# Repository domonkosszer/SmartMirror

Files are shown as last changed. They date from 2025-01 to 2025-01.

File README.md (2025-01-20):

# SmartMirror

Our project aims to develop an innovative Smart Mirror, enhanced with touchscreen interactivity through infrared light technology. By integrating both emitters and receivers of infrared light, the touchscreen detects user interactions by identifying interruptions in the light beams, enabling accurate coordinate detection. The primary goal is to create an interactive mirror featuring a display that responds seamlessly to touch inputs. This will allow users to interact with the display and switch between various applications.

To streamline the design and avoid tangled cables, we decided to solder all the connections. However, the soldering process proved more challenging than anticipated, preventing us from achieving the desired results. Additionally, we encountered issues with a loose connection to the screen, which led to flickering and occasional display anomalies, including distorted lighting effects.

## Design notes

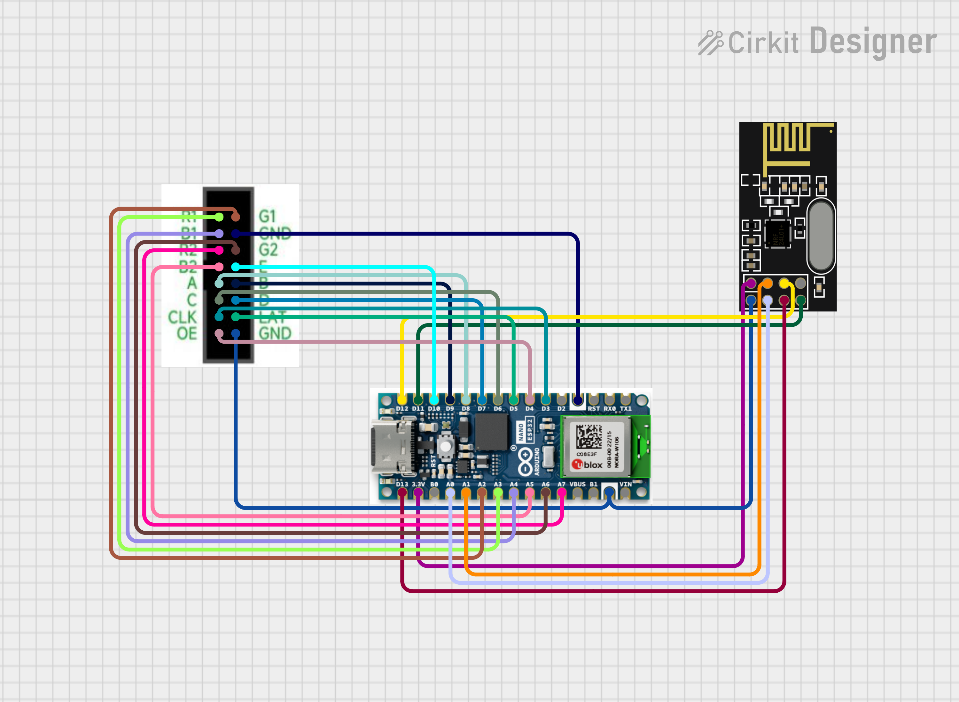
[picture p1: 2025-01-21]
images/circuit_image MainHub.png

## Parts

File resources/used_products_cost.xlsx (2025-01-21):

Quantity | Need | Buffer | Item | URL | Prize
1 | 1 | 0 | Mineralglas 40cm x 30cm | https://www.jumbo.ch/de/bauen-renovieren/glas-kunstglas/kunstglas/mineralglas--40--30-cm/p/3227387 | CHF 6.20
5 | 5 | 0 | NRF24L01 | https://de.aliexpress.com/item/1005005642753224.html
10 | 8 | 2 | Prototype Boards 2 cm x 8 cm | https://de.aliexpress.com/item/1005007204340724.html
5 | 4 | 1 | Prototype Boards 4 cm x 6 cm | https://de.aliexpress.com/item/1005007204340724.html
20 | 12 | 8 | Multiplexer CD4051BE | https://de.aliexpress.com/item/1005002394795142.html
4 | 4 | 0 | Typ-C Nano 3.0-Controller für Arduino CH340 USB-Treiber | https://de.aliexpress.com/item/1005007066680464.html
10 | 4 | 6 | 10uf 400V Kondensator | https://de.aliexpress.com/item/1005004387892193.html | V
1 | 1 | 0 | Matrix-LED-Bildschirm 64 pixel x 64 pixel | https://de.aliexpress.com/item/1005007767387150.html | CHF 31.86
100 | 96 | 4 | 5mm Infra-Red Emitters | https://amzn.eu/d/e0SbXlf
100 | 96 | 4 | 5mm Infra-Red Phototransistors | https://amzn.eu/d/bf8DKLu | V
100 | 96 | 4 | 100k Ohm Resistors | https://amzn.eu/d/hSxaTXH | CHF 16.87
1 | 1 | 0 | Hohlstecker DC 5.5 x 2.1 mm Buchse | https://www.fust.ch/de/p/tv-foto-gaming/kabel-haustechnik/stromkabel-stromzubehoer/netzteile/delock/hohlstecker-dc-5-5-x-2-1-mm-buchse-terminalblock-2-pin-862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 | CHF 0.50
1 | 1 | 0 | NodeMCU-32S, ESP32 WiFi+Bluetooth Development Board | https://www.waveshare.com/nodemcu-32s.htm | CHF 13.16
1 | 1 | 0 | C 110V-220V zu DC 5V 10A Netzteil | https://de.aliexpress.com/item/1005004458821253.html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
1 | 1 | 0 | Multi 4 in 1 USB C Lange Ladegerät Ladekabel | Multi 4 in 1 USB C Lange Ladegerät Ladekabel Mehrere Ports Lade Kabel Typ C Stecker für Handys - AliExpress 509 (https://de.aliexpress.com/item/1005004444269560.html)
50 | 20 | 30 | 100 Ohm Resistors | https://de.aliexpress.com/item/1005007010335100.html
1 | 1 | 0 | Kupferdraht 5m 20AWG | RV-Kupferdraht, flexibles Kabel, elektrisches PVC-Elektrokabel, 300/500 V, einadriger, mehradriger, flexibler Draht für Auto-Audio-Kabel - AliExpress 13 (https://de.aliexpress.com/item/1005005995948905.html) | V
1 | 1 | 0 | Isolierband 9mm 10m | Isolierband hitze beständiges Kabelbaum klebeband Klebeband wasserdichtes Klebeband isolierendes Kfz-Stoffband 5-tlg - AliExpress (https://de.aliexpress.com/item/1005007005495930.html) | CHF 15.16
1 | 1 | 0 | Mirror Foil | https://www.foliencenter24.com/solar-screen-alu-80c-sonnenschutzfolie-76cm | CHF 8.58
1 | 1 | 0 | Arduino Nano ESP32 | https://www.digitec.ch/de/s1/product/arduino-nano-esp32-with-headers-entwicklungsboard-kit-37112615 | CHF 23.90
 |  |  |  | Total cost: | CHF 116.23

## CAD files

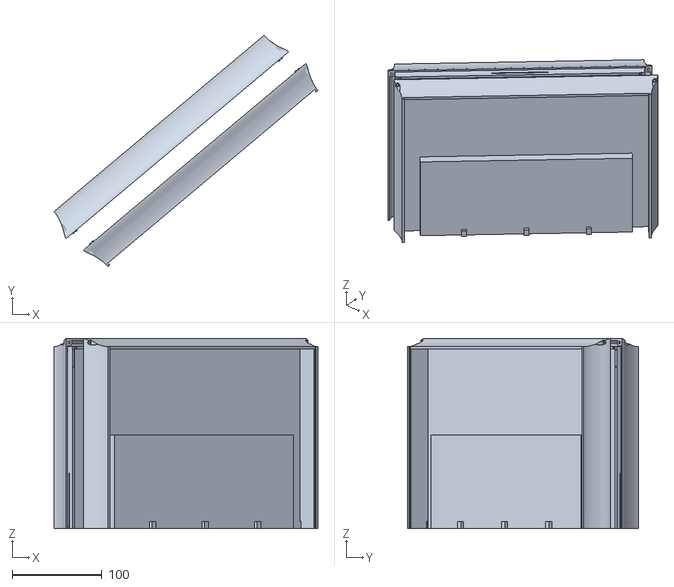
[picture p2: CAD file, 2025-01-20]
3D_models/Box_for_printing.stl
294.5 x 258.2 x 212.0

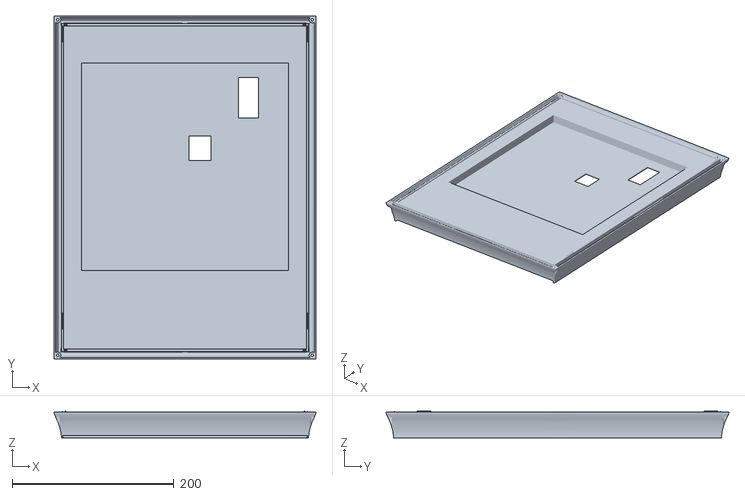
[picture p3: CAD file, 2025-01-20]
3D_models/Box.stl
324.0 x 424.0 x 33.1

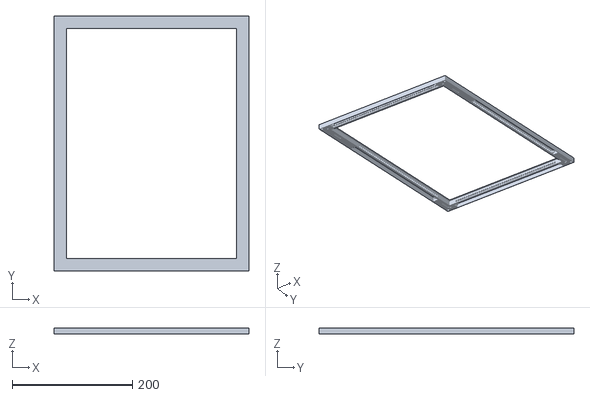
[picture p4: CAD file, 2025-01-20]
3D_models/Frame.stl
324.0 x 424.0 x 10.0

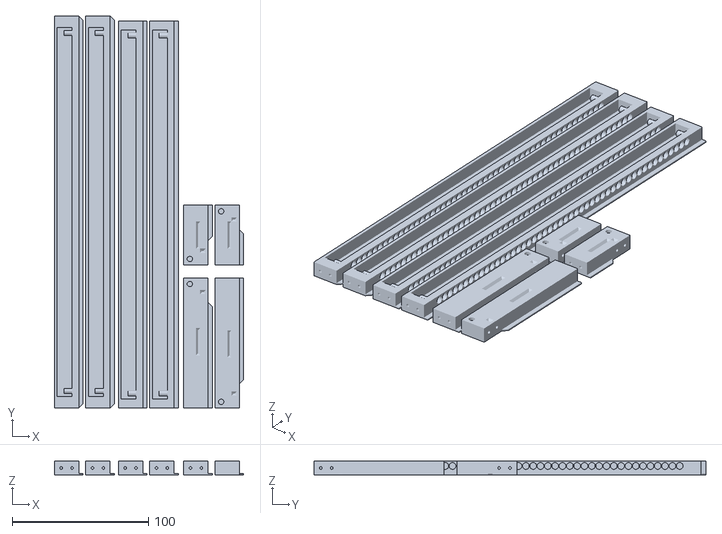
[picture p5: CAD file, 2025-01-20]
3D_models/Frame_for_printing.stl
139.0 x 288.0 x 10.0

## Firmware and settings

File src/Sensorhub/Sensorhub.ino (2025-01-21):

#include<SPI.h> 
#include<nRF24L01.h> 
#include<RF24.h> 
 
 
//enclosed is the code for multiplexer switching 
byte controlPinsLoneMux[] = {B00000000, //using switched digital pins to set the mux pins from 0-7 //enclosed is the code for multiplexer switching 
                             B10000000, //7.6.5.4.3.2.1.0 
                             B01000000, 
                             B11000000, 
                             B00100000, 
                             B10100000, 
                             B01100000, 
                             B11100000 
                            }; 
int muxValues[] = {0, 0, 0, 0, 0, 0, 0, 0, 0, 0, 0, 0, 0, 0, 0, 0, 0, 0, 0, 0, 0, 0, 0, 0}; 
int muxValuesA[] = {0, 0, 0, 0, 0, 0, 0, 0}; //holding  1-8 
int muxValuesB[] = {0, 0, 0, 0, 0, 0, 0, 0}; //holding  9-17 
int muxValuesC[] = {0, 0, 0, 0, 0, 0, 0, 0}; //holding  18-24 


int muxValuesZ[] = {0, 0, 0, 0, 0, 0, 0, 0, 0, 0, 0, 0, 0, 0, 0, 0, 0, 0, 0, 0, 0, 0, 0, 0};
byte muxValuesZA[] = {0, 0, 0, 0, 0, 0, 0, 0}; //holding  1-8 
byte muxValuesZB[] = {0, 0, 0, 0, 0, 0, 0, 0}; //holding  9-17 
byte muxValuesZC[] = {0, 0, 0, 0, 0, 0, 0, 0}; //holding  18-24 

int calValues[] = {0, 0, 0, 0, 0, 0, 0, 0, 0, 0, 0, 0, 0, 0, 0, 0, 0, 0, 0, 0, 0, 0, 0, 0}; 
int calValuesA[] = {0,0,0,0,0,0,0,0};
int calValuesB[] = {0,0,0,0,0,0,0,0};
int calValuesC[] = {0,0,0,0,0,0,0,0};

int calValuesZ[] = {0, 0, 0, 0, 0, 0, 0, 0, 0, 0, 0, 0, 0, 0, 0, 0, 0, 0, 0, 0, 0, 0, 0, 0}; 
int calValuesZA[] = {0,0,0,0,0,0,0,0};
int calValuesZB[] = {0,0,0,0,0,0,0,0};
int calValuesZC[] = {0,0,0,0,0,0,0,0};

bool lowSensors = false;
float lTouch = 0;
unsigned long lTtime = 0;
unsigned long lTclock = 0;
bool reset = true;

bool lowSensorsZX = false;
float lTouchZX = 0;
unsigned long lTtimeZX = 0;
unsigned long lTclockZX = 0;
bool resetZX = true;
 
int calibrate; 
int buttonPin = 14; 
bool printing; 
int calibrated; 
int eight; 
bool expiredCal; 
bool firstWrng; 
bool autocalibration = false; 
bool push; 
long OutputInterval = 1500; 
unsigned long rStart = 0;
long rIntrvl = 60000;
unsigned long BaseTime; 
unsigned long CurrentTime; 
unsigned long PreviousTime; 
unsigned long expired; 
bool expire; 
bool printrecal; 
unsigned long lastwrng; 
unsigned long calStart; 
unsigned long wrngStrt; 
unsigned int wrngIntrvl = 900000 /*30000*/; 
unsigned int expireIntrvl =  7200000 /*60000*/; 
bool adjusted = false;
unsigned long expireStrt; 
unsigned long expireLst; 
bool aligned; 
bool pushed; 
double IRsetting; 
bool calibrationStored = false;
bool calibratedZ = false;
unsigned long powerOnTime = 0;
long selfAdjTime = 500;
bool selfCal = false;

bool n = false;
bool t = false;
bool c = false;
bool d = false;
bool b = false;
bool z = false;
bool y = false;
bool r = false;

bool cPrinted = true;
bool dPrinted = true;
bool wrote = false;

unsigned long StartTime; 

int LowX = 0;
int Low1X = 0;
int Low2X = 0;
int Low3X = 0;
int Low4X = 0;
int lTrend = 0;
float lastX = 0;
float lastY = 0;

int highTouch1 = 0;
int highTouch2 = 0;
int highTouch3 = 0;
int lowTouch1 = 0;
int lowTouch2 = 0;
int lowTouch3 = 0;
int lastDiff = 0;
int currentDiff = 0;

int LowZX = 0;
int Low1ZX = 0;
int Low2ZX = 0;
int Low3ZX = 0;
int Low4ZX = 0;
int lTrendZX = 0;
float lastZX = 0;

int highTouch1ZX = 0;
int highTouch2ZX = 0;
int highTouch3ZX = 0;
int lowTouch1ZX = 0;
int lowTouch2ZX = 0;
int lowTouch3ZX = 0;
int lastDiffZX = 0;
int currentDiffZX = 0;

const int calTime = 2000; 
unsigned long currentCal; 
 
RF24 radio(8,9); 
 
//const uint64_t wAddress[] = {0xD31373D0B2LL};

const byte address[6] = "00001";

  
//const byte rxAddr[6] = "TRAN1"; 
 
void setup() { 
  Serial.begin(9600);
  radio.begin();
  radio.openWritingPipe(address);
  radio.setChannel(5);           
  radio.setDataRate(RF24_1MBPS);
  radio.setPALevel(RF24_PA_LOW);
  
  radio.stopListening();

  Serial.println("Transmitter ready.");


  DDRD = B11100000; //setting digital pins 6-4 to HIGH 
  BaseTime = millis(); 
  //pinMode(buttonPin, INPUT); 
  //pinMode(6, OUTPUT);
  //pinMode(5, OUTPUT); 
  //pinMode(4, OUTPUT); 
  pinMode(10, OUTPUT); 
  pinMode(14, OUTPUT);  //receivers
  digitalWrite(14, HIGH); 
  pinMode(15, OUTPUT);  //receivers
  digitalWrite(15, HIGH); 
} 
 
void setPinMux(int outputMuxPin) { 
  PORTD = controlPinsLoneMux[outputMuxPin];       //setting sewdxa{;;e'f}digital 4-6 to follow the truth table instructions 
 
} 

void muxVals() {
  Serial.println();
  Serial.println(F("Values for multiplexer:"));
  Serial.println(F("==========================="));
  for (int a = 0; a < 24; a++) {
    Serial.print(a);
    Serial.print(F(" = "));
    Serial.println(muxValues[a]);
  }
  Serial.println(F("==========================="));
} 

void muxValsZ() {
  Serial.println();
  Serial.println(F("Values for multiplexer Z:"));
  Serial.println(F("==========================="));
  for (int a = 0; a < 24; a++) {
    Serial.print(a);
    Serial.print(F(" = "));
    Serial.println(muxValuesZ[a]);
  }
  Serial.println(F("==========================="));
} 
 
void calVals() { 
  Serial.println(); 
  Serial.println(F("Calibrated Values:")); 
  Serial.println(F("===========================")); 
  for (int a = 0; a < 24; a++) { 
    Serial.print(a); 
    Serial.print(F(" = ")); 
    Serial.println(calValues[a]); 
  } 
  Serial.println(F("===========================")); 
} 

void calMuxDiff() { 
  Serial.println(); 
  Serial.println(F("Current Difference Between Calibrated Values and Current Values:")); 
  Serial.println(F("===========================")); 
 for (int a = 0; a < 24; a++){ 
    Serial.print(a); 
    Serial.print(F(" = ")); 
    Serial.println(muxValues[a] - calValues[a]); 
 }
  Serial.println(F("==========================="));
}

void calMuxDiffZA() { 
  Serial.println(); 
  Serial.println(F("Current Difference Between Calibrated Values and Current ZY Values:")); 
  Serial.println(F("===========================")); 
 for (int a = 0; a < 8; a++){ 
    Serial.print(a); 
    Serial.print(F(" = ")); 
    Serial.println(muxValuesZA[a] - calValuesA[a]); 
 }
  Serial.println(F("===========================")); 
}

void calMuxDiffZB(){
 for (int a = 0; a < 8; a++){
  for (int b = 8; b <16; b++){ 
  if ( a == 0 && b == 8){
    Serial.print(b); 
    Serial.print(F(" = ")); 
    Serial.println(muxValuesZB[a] - calValuesZB[a]);
  } 
  if ( a == 1 && b == 9){
    Serial.print(b); 
    Serial.print(F(" = ")); 
    Serial.println(muxValuesZB[a] - calValuesZB[a]);
  } 
  if ( a == 2 && b == 10){
    Serial.print(b); 
    Serial.print(F(" = ")); 
    Serial.println(muxValuesZB[a] - calValuesZB[a]);
  } 
  if ( a == 3 && b == 11){
    Serial.print(b); 
    Serial.print(F(" = ")); 
    Serial.println(muxValuesZB[a] - calValuesZB[a]);
  } 
  if ( a == 4 && b == 12){
    Serial.print(b); 
    Serial.print(F(" = ")); 
    Serial.println(muxValuesZB[a] - calValuesZB[a]);
  } 
  if ( a == 5 && b == 13){
    Serial.print(b); 
    Serial.print(F(" = ")); 
    Serial.println(muxValuesZB[a] - calValuesZB[a]);
  } 
  if ( a == 6 && b == 14){
    Serial.print(b); 
    Serial.print(F(" = ")); 
    Serial.println(muxValuesZB[a] - calValuesZB[a]);
  } 
  if ( a == 7 && b == 15){
    Serial.print(b); 
    Serial.print(F(" = ")); 
    Serial.println(muxValuesZB[a] - calValuesZB[a]);
  } 
 }
 }
  Serial.println(F("==========================="));
  
}

void calMuxDiffZC(){
 for (int a = 0; a < 8; a++){ 
  for (int b = 16; b < 24; b++){
   if ( a == 0 && b == 16){
    Serial.print(b); 
    Serial.print(F(" = ")); 
    Serial.println(muxValuesZC[a] - calValuesZC[a]); 
   }
   if ( a == 1 && b == 17){
    Serial.print(b); 
    Serial.print(F(" = ")); 
    Serial.println(muxValuesZC[a] - calValuesZC[a]); 
   }
   if ( a == 2 && b == 18){
    Serial.print(b); 
    Serial.print(F(" = ")); 
    Serial.println(muxValuesZC[a] - calValuesZC[a]); 
   }
   if ( a == 3 && b == 19){
    Serial.print(b); 
    Serial.print(F(" = ")); 
    Serial.println(muxValuesZC[a] - calValuesZC[a]); 
   }
   if ( a == 4 && b == 20){
    Serial.print(b); 
    Serial.print(F(" = ")); 
    Serial.println(muxValuesZC[a] - calValuesZC[a]); 
   }
   if ( a == 5 && b == 21){
    Serial.print(a); 
    Serial.print(F(" = ")); 
    Serial.println(muxValuesZC[a] - calValuesZC[a]); 
   }
   if ( a == 6 && b == 22){
    Serial.print(b); 
    Serial.print(F(" = ")); 
    Serial.println(muxValuesZC[a] - calValuesZC[a]); 
   }
   if ( a == 7 && b == 23){
    Serial.print(b); 
    Serial.print(F(" = ")); 
    Serial.println(muxValuesZC[a] - calValuesZC[a]); 
   }
 }
 }
  Serial.println(F("===========================")); 
}

  void muxValsZ3() { 
  for (int c1 = 0; c1 < 8; c1++) { 
  for (int c = 16; c < 24; c++) { 
  if (c == 16 && c1 == 0){ 
    Serial.print(F("ZX"));
    Serial.print(c); 
    Serial.print(F(" = "));  
    Serial.println(muxValuesZC[c1]); 
  } 
  if (c == 17 && c1 == 1){ 
    Serial.print(F("ZX"));
    Serial.print(c); 
    Serial.print(F(" = "));  
    Serial.println(muxValuesZC[c1]); 
  } 
  if (c == 18 && c1 == 2){ 
    Serial.print(F("ZX"));
    Serial.print(c); 
    Serial.print(F(" = "));  
    Serial.println(muxValuesZC[c1]); 
  } 
  if (c == 19 && c1 == 3){
    Serial.print(F("ZX")); 
    Serial.print(c); 
    Serial.print(F(" = "));  
    Serial.println(muxValuesZC[c1]); 
  } 
  if (c == 20 && c1 == 4){ 
    Serial.print(F("ZX"));
    Serial.print(c); 
    Serial.print(F(" = "));  
    Serial.println(muxValuesZC[c1]); 
  } 
  if (c == 21 && c1 == 5){ 
    Serial.print(F("ZX"));
    Serial.print(c); 
    Serial.print(F(" = "));  
    Serial.println(muxValuesZC[c1]); 
  } 
  if (c == 22 && c1 == 6){ 
    Serial.print(F("ZX"));
    Serial.print(c); 
    Serial.print(F(" = "));  
    Serial.println(muxValuesZC[c1]); 
  } 
  if (c == 23 && c1 == 7){
    Serial.print(F("ZX")); 
    Serial.print(c); 
    Serial.print(F(" = "));  
    Serial.println(muxValuesZC[c1]); 
  } 
  } 
  }  
     
   
  Serial.println(F("===========================")); 
} 
 

 
void timeloop(){ 
currentCal = millis(); 
} 

bool calArray (){
LowX = 0;
Low1X = 0;
Low2X = 0;
Low3X = 0;
Low4X = 0;

LowZX = 0;
Low1ZX = 0;
Low2ZX = 0;
Low3ZX = 0;
Low4ZX = 0;

int threesX = 0;
int twoosX = 0;
int onesX = 0;
int zeroesX = 0;

int threesZX = 0;
int twoosZX = 0;
int onesZX = 0;
int zeroesZX = 0;

bool low = true;
bool paired = false;
   
   calValues[0] = muxValues[0];
   calValues[1] = muxValues[1];
   calValues[2] = muxValues[2];
   calValues[3] = muxValues[3];
   calValues[4] = muxValues[4];
   calValues[5] = muxValues[5];
   calValues[6] = muxValues[6];
   calValues[7] = muxValues[7];
   calValues[8] = muxValues[8];
   calValues[9] = muxValues[9];
   calValues[10] = muxValues[10];
   calValues[11] = muxValues[11];
   calValues[12] = muxValues[12];
   calValues[13] = muxValues[13];
   calValues[14] = muxValues[14];
   calValues[15] = muxValues[15];
   calValues[16] = muxValues[16];
   calValues[17] = muxValues[17];
   calValues[18] = muxValues[18];
   calValues[19] = muxValues[19];
   calValues[20] = muxValues[20];
   calValues[21] = muxValues[21];
   calValues[22] = muxValues[22];
   calValues[23] = muxValues[23];

   calValuesZ[0] = muxValuesZ[0];
   calValuesZ[1] = muxValuesZ[1];
   calValuesZ[2] = muxValuesZ[2];
   calValuesZ[3] = muxValuesZ[3];
   calValuesZ[4] = muxValuesZ[4];
   calValuesZ[5] = muxValuesZ[5];
   calValuesZ[6] = muxValuesZ[6];
   calValuesZ[7] = muxValuesZ[7];
   calValuesZ[8] = muxValuesZ[8];
   calValuesZ[9] = muxValuesZ[9];
   calValuesZ[10] = muxValuesZ[10];
   calValuesZ[11] = muxValuesZ[11];
   calValuesZ[12] = muxValuesZ[12];
   calValuesZ[13] = muxValuesZ[13];
   calValuesZ[14] = muxValuesZ[14];
   calValuesZ[15] = muxValuesZ[15];
   calValuesZ[16] = muxValuesZ[16];
   calValuesZ[17] = muxValuesZ[17];
   calValuesZ[18] = muxValuesZ[18];
   calValuesZ[19] = muxValuesZ[19];
   calValuesZ[20] = muxValuesZ[20];
   calValuesZ[21] = muxValuesZ[21];
   calValuesZ[22] = muxValuesZ[22];
   calValuesZ[23] = muxValuesZ[23];

for (int a:calValuesA){
  if (a == 0) ++zeroesX;
  if (a == 1) ++onesX;
  if (a == 2) ++twoosX;
  if (a == 3) ++threesX;
}

for (int b:calValuesB){
  if (b == 0) ++zeroesX;
  if (b == 1) ++onesX;
  if (b == 2) ++twoosX;
  if (b == 3) ++threesX;
}

for (int c:calValuesC){
  if (c == 0) ++zeroesX;
  if (c == 1) ++onesX;
  if (c == 2) ++twoosX;
  if (c == 3) ++threesX;
}

for (int a:calValuesZA){
  if (a == 0) ++zeroesZX;
  if (a == 1) ++onesZX;
  if (a == 2) ++twoosZX;
  if (a == 3) ++threesZX;
}

for (int b:calValuesZB){
  if (b == 0) ++zeroesZX;
  if (b == 1) ++onesZX;
  if (b == 2) ++twoosZX;
  if (b == 3) ++threesZX;
}

for (int c:calValuesZC){
  if (c == 0) ++zeroesZX;
  if (c == 1) ++onesZX;
  if (c == 2) ++twoosZX;
  if (c == 3) ++threesZX;
}
  calibrationStored = true;
  paired = true;   
  low = false;  
Serial.println();
Serial.print(F("Calibration Successful! "));

Serial.println();
Serial.print("Calibration Failed!");

Serial.println();
Serial.print("There are this many zeroes for X: ");
Serial.print(zeroesX);

Serial.println();
Serial.print("There are this many ones for X: ");
Serial.print(onesX);
    
Serial.println();
Serial.print("There are this many twoos for X: ");
Serial.print(twoosX);
  
Serial.println();
Serial.print("There are this many threes for X: ");
Serial.print(threesX);

Serial.println();
Serial.print("There are this many zeroes for ZX: ");
Serial.print(zeroesZX);

Serial.println();
Serial.print("There are this many ones for ZX: ");
Serial.print(onesZX);
    
Serial.println();
Serial.print("There are this many twoos for ZX: ");
Serial.print(twoosZX);
  
Serial.println();
Serial.print("There are this many threes for ZX: ");
Serial.print(threesZX);

return paired; 
}

void loop() {   
lTclock = millis();

char input = 'O';
bool written = true;

float TouchedX = {0};
float TouchedZX = {0};
bool TouchX = false;
bool TouchZX = false;
bool tapped = false;  
unsigned long tappedTime = NULL;  
bool fingerDown = false;  

float touchedValuesX[] = {0,0,0,0,0,0,0,0,0,0,0,0,0,0,0,0,0,0,0,0,0,0,0,0};
float touchedValuesZX[] = {0,0,0,0,0,0,0,0,0,0,0,0,0,0,0,0,0,0,0,0,0,0,0,0};
float sendingX[] = {0,0}; 
float sendingZX[] = {0,0};     
  
bool sent = false;
 
byte message = 3; 

CurrentTime = millis(); 
calibrate = digitalRead(buttonPin); 
     
if (autocalibration == true){ 
expire = false; 
autocalibration = false; 
calStart = millis(); 
expireStrt = millis(); 
push = true; 
pushed = true; 
expire = false; 
firstWrng = false; 
calibrated = 2; 
calArray();
} 
   
if(calibrate == HIGH){ // added for the recal printing glitch 
 printrecal = false;   
  } 

 while (pushed == true){ 
  currentCal = millis(); 
  BaseTime = millis(); 
Serial.flush(); 
Serial.println();   
if (printrecal == false){ 
Serial.print(F("Calibrating..."));  
} 
else { 
  Serial.print(F("Auto-recalibrating...")); 
}  
if (currentCal <= calStart + calTime){   
    pushed = false; ;  
  } 
 }
   

if (CurrentTime - expireStrt >= 7200000 && CurrentTime - expireStrt >= expireIntrvl && firstWrng != true ){  
Serial.println(); 
Serial.print(F("It has been 2 hours since the last calibration, you should consider recalibrating.")); 
expireStrt = millis(); 
expired = millis(); 
expire = true; 
firstWrng = true; 
wrngStrt = millis(); 
calibrated = 1; 
} 
 
if (firstWrng == true && CurrentTime - wrngIntrvl >= wrngStrt ){ 
Serial.println(); 
Serial.print(F("Recalibration recommended!")); 
wrngStrt = millis(); 
lastwrng = millis(); 
 
    } 
 
 if (expire == true && CurrentTime - 1860000 >= expired && expired > 1) { // expired > 1 added for gltch 
  autocalibration = true; 
  printrecal = true; 
 }  
 
if (expire == true && CurrentTime - 7200000 >= expired){ 
  calibrated = 0; 
} 
for(int b = 8; b < 24; b ++){
 for (int a = 0; a < 8; a++) { 
    setPinMux(a);
    muxValuesZ[a] = analogRead(2);
    muxValues[a] = analogRead(5);
    if( a == 0 && b == 8){
      muxValues[b] =  analogRead(6);
      muxValuesZ[b] =  analogRead(3);
    }
    if( a == 1 && b == 9){
      muxValues[b] =  analogRead(6);
      muxValuesZ[b] =  analogRead(3);
    }
    if( a == 2 && b == 10){
      muxValues[b] =  analogRead(6);
      muxValuesZ[b] =  analogRead(3);
    }
    if( a == 3 && b == 11){
      muxValues[b] =  analogRead(6);
      muxValuesZ[b] =  analogRead(3);
    }
    if( a == 4 && b == 12){
      muxValues[b] =  analogRead(6);
      muxValuesZ[b] =  analogRead(3);
    }
    if( a == 5 && b == 13){
      muxValues[b] =  analogRead(6);
      muxValuesZ[b] =  analogRead(3);
    }
    if( a == 6 && b == 14){
      muxValues[b] =  analogRead(6);
      muxValuesZ[b] =  analogRead(3);
    }
    if( a == 7 && b == 15){
      muxValues[b] =  analogRead(6);
      muxValuesZ[b] =  analogRead(3);
    }
    if( a == 0 && b == 16){
      muxValues[b] =  analogRead(7);
      muxValuesZ[b] =  analogRead(4);
    }
    if( a == 1 && b == 17){
      muxValues[b] =  analogRead(7);
      muxValuesZ[b] =  analogRead(4);
    }
    if( a == 2 && b == 18){
      muxValues[b] =  analogRead(7);
      muxValuesZ[b] =  analogRead(4);
    }
    if( a == 3 && b == 19){
      muxValues[b] =  analogRead(7);
      muxValuesZ[b] =  analogRead(4);
    }
    if( a == 4 && b == 20){
      muxValues[b] =  analogRead(7);
      muxValuesZ[b] =  analogRead(4);
    }
    if( a == 5 && b == 21){
      muxValues[b] =  analogRead(7);
      muxValuesZ[b] =  analogRead(4);
    }
    if( a == 6 && b == 22){
      muxValues[b] =  analogRead(7);
      muxValuesZ[b] =  analogRead(4);
    }
    if( a == 7 && b == 23){
      muxValues[b] =  analogRead(7);
      muxValuesZ[b] =  analogRead(4);
    }
 }
  
  } 

int touched1[] = {0,0,0,0,0,0,0,0,0,0,0,0,0,0,0,0,0,0,0,0,0,0,0,0};
int touched[] = {0,0,0,0,0,0,0,0,0,0,0,0,0,0,0,0,0,0,0,0,0,0,0,0};
int touched4[] = {0,0,0,0,0,0,0,0,0,0,0,0,0,0,0,0,0,0,0,0,0,0,0,0};
int touched5[] = {0,0,0,0,0,0,0,0,0,0,0,0,0,0,0,0,0,0,0,0,0,0,0,0};
int touched6[] = {0,0,0,0,0,0,0,0,0,0,0,0,0,0,0,0,0,0,0,0,0,0,0,0};
int touched3[] = {0,0,0,0,0,0,0,0,0,0,0,0,0,0,0,0,0,0,0,0,0,0,0,0};
int fourTouches = 0;
int threeTouches = 0;
int fiveTouches = 0;
int twoTouches = 0;
int oneTouches = 0;
int fourTouch = 0;
int threeTouch = 0;
int fiveTouch = 0;
int twoTouch = 0;
int oneTouch = 0;
float touchedValuesY[] = {0,0,0,0,0,0,0,0,0,0,0,0,0,0,0,0,0,0,0,0,0,0,0,0};
float rTouchedValuesY[] = {0,0,0,0,0,0,0,0,0,0,0,0,0,0,0,0,0,0,0,0,0,0,0,0};
bool noPrint = false;
int group[] = {-1,-1,-1,-1,-1,-1,-1,-1,-1,-1,-1,-1,-1,-1,-1,-1,-1,-1,-1,-1,-1,-1,-1,-1};
float adjustedGroup[] = {0,0,0,0,0,0,0,0,0,0,0,0,0,0,0,0,0,0,0,0,0,0,0,0};
float adjustedDiff[] = {0,0,0,0,0,0,0,0,0,0,0,0,0,0,0,0,0,0,0,0,0,0,0,0};
float adjustedCalibrated[] = {0,0,0,0,0,0,0,0,0,0,0,0,0,0,0,0,0,0,0,0,0,0,0,0};
float groupCoef[] = {0,0,0,0,0,0,0,0,0,0,0,0,0,0,0,0,0,0,0,0,0,0,0,0};
int low[] = {-1,-1,-1,-1,-1,-1,-1,-1,-1,-1,-1,-1,-1,-1,-1,-1,-1,-1,-1,-1,-1,-1,-1,-1};
int bLow[] = {0,0,0,0,0,0,0,0,0,0,0,0,0,0,0,0,0,0,0,0,0,0,0,0};
int highestVariance = 0;
int highestPoint = 0;
int calibratedHighestPoint = 0;
bool done = false;
int touch = 25;
int down = 0;
int currentHighestGroup = -1;
float percentTouch[] = {0,0,0,0,0,0,0,0,0,0,0,0,0,0,0,0,0,0,0,0,0,0,0,0};
int lowCons[] = {0,0,0};
int highCons[] = {0,0,0};
int replaced[] = {0,0,0,0};
int calculatedReplace = 0;
bool addHalf = false;
bool subHalf = false;
int secondTouch = 50;

float rtouchedValuesX[] = {0,0,0,0,0,0,0,0,0,0,0,0,0,0,0,0,0,0,0,0,0,0,0,0};

int touched1ZX[] = {0,0,0,0,0,0,0,0,0,0,0,0,0,0,0,0,0,0,0,0,0,0,0,0};
int touchedZX[] = {0,0,0,0,0,0,0,0,0,0,0,0,0,0,0,0,0,0,0,0,0,0,0,0};
int touched4ZX[] = {0,0,0,0,0,0,0,0,0,0,0,0,0,0,0,0,0,0,0,0,0,0,0,0};
int touched5ZX[] = {0,0,0,0,0,0,0,0,0,0,0,0,0,0,0,0,0,0,0,0,0,0,0,0};
int touched6ZX[] = {0,0,0,0,0,0,0,0,0,0,0,0,0,0,0,0,0,0,0,0,0,0,0,0};
int touched3ZX[] = {0,0,0,0,0,0,0,0,0,0,0,0,0,0,0,0,0,0,0,0,0,0,0,0};
int fourTouchesZX = 0;
int threeTouchesZX = 0;
int fiveTouchesZX = 0;
int twoTouchesZX = 0;
int oneTouchesZX = 0;
int fourTouchZX = 0;
int threeTouchZX = 0;
int fiveTouchZX = 0;
int twoTouchZX = 0;
int oneTouchZX = 0;
float touchedValuesZXY[] = {0,0,0,0,0,0,0,0,0,0,0,0,0,0,0,0,0,0,0,0,0,0,0,0};
float rTouchedValuesZXY[] = {0,0,0,0,0,0,0,0,0,0,0,0,0,0,0,0,0,0,0,0,0,0,0,0};
bool noPrintZX = false;
int groupZX[] = {-1,-1,-1,-1,-1,-1,-1,-1,-1,-1,-1,-1,-1,-1,-1,-1,-1,-1,-1,-1,-1,-1,-1,-1};
float adjustedGroupZX[] = {0,0,0,0,0,0,0,0,0,0,0,0,0,0,0,0,0,0,0,0,0,0,0,0};
float adjustedDiffZX[] = {0,0,0,0,0,0,0,0,0,0,0,0,0,0,0,0,0,0,0,0,0,0,0,0};
float adjustedCalibratedZX[] = {0,0,0,0,0,0,0,0,0,0,0,0,0,0,0,0,0,0,0,0,0,0,0,0};
float groupCoefZX[] = {0,0,0,0,0,0,0,0,0,0,0,0,0,0,0,0,0,0,0,0,0,0,0,0};
int lowZX[] = {-1,-1,-1,-1,-1,-1,-1,-1,-1,-1,-1,-1,-1,-1,-1,-1,-1,-1,-1,-1,-1,-1,-1,-1};
int bLowZX[] = {0,0,0,0,0,0,0,0,0,0,0,0,0,0,0,0,0,0,0,0,0,0,0,0};
int highestVarianceZX =0;
int highestPointZX = 0;
int calibratedHighestPointZX = 0;
bool doneZX = false;
int touchZ = 25;
int downZX = 0;
int currentHighestGroupZX = 0;
float percentTouchZX[] = {0,0,0,0,0,0,0,0,0,0,0,0,0,0,0,0,0,0,0,0,0,0,0,0};
int lowConsZX[] = {0,0,0};
int highConsZX[] = {0,0,0};
int replacedZX[] = {0,0,0,0};
int calculatedReplaceZX = 0;
bool addHalfZX = false;
bool subHalfZX = false;
int secondTouchZX = 50;
float rtouchedValuesZX[] = {0,0,0,0,0,0,0,0,0,0,0,0,0,0,0,0,0,0,0,0,0,0,0,0};

if (calibrationStored == true){ 

   for (int a = 0; a <24; a++){
    
 if (muxValues[a] <= calValues[a] - 4){
n = false;
down++;  
  if (low[0] != -1 && low[1] != -1 && low[2] != -1 && low[3] != -1 && low[4] != -1 && low[5] != -1 && low[6] != -1 && low[7] != -1 && low[8] != -1 && low[9] == -1){

low[9] = a;

group[a] = muxValues[a];

}

if (low[0] != -1 && low[1] != -1 && low[2] != -1 && low[3] != -1 && low[4] != -1 && low[5] != -1 && low[6] != -1 && low[7] != -1 && low[8] == -1 && low[9] == -1){

low[8] = a;

group[a] = muxValues[a];
}

if (low[0] != -1 && low[1] != -1 && low[2] != -1 && low[3] != -1 && low[4] != -1 && low[5] != -1 && low[6] != -1 && low[7] == -1 && low[8] == -1 && low[9] == -1){

low[7] = a;
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

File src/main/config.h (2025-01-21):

#ifndef CONFIG_H
#define CONFIG_H

// NTP
#define NTP_INTERVAL 3600
#define NTP_ADDRESS "pool.ntp.org"
#define NTP_OFFSET 3600

// Panel dimensions
#define PANEL_WIDTH   64
#define PANEL_HEIGHT  64

// Delay in ms for clock animation
#define CLOCK_ANIMATION_DELAY_MSEC 20

// Day of week
#define DOW_X 0
#define DOW_Y 0

// Day of week color
#define DOW_COLOR ((0x00 & 0xF8) << 8) | ((0x40 & 0xFC) << 3) | (0xFF >> 3)

// Date
#define DATE_X DOW_X
#define DATE_Y DOW_Y+11

// Date color
#define DATE_COLOR DOW_COLOR

// Width and height are for both DATE and DOW
#define DATE_WIDTH  40
#define DATE_HEIGHT 18

#define BITMAP_X 0
#define BITMAP_Y 44

// Clock
#define CLOCK_X 0
#define CLOCK_Y 24
#define CLOCK_SEGMENT_HEIGHT 6
#define CLOCK_SEGMENT_WIDTH  6
#define CLOCK_SEGMENT_SPACING 4
#define CLOCK_WIDTH  6*(CLOCK_SEGMENT_WIDTH+CLOCK_SEGMENT_SPACING)+4
#define CLOCK_HEIGHT 2*CLOCK_SEGMENT_HEIGHT+3

// Clock color
#define CLOCK_DIGIT_COLOR  ((0x00 & 0xF8) << 8) | ((0xFF & 0xFC) << 3) | (0xFF >> 3)

#endif

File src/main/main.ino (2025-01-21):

#include <Ticker.h>

#include "config.h"
#include "main.h"
#include "setup.h"
#include "display.h"
#include "clock.h"
#include "time.h"
#include "weather.h"
#include "touch.h"

Ticker displayTicker;
unsigned long prevEpoch;
unsigned long lastNTPUpdate;

bool isClock = true;
bool isWeather = false;

void setup(){
  Serial.begin(115200);
  delay(10);

  display_init();
  Serial.println("Display initialized.");

  touch_init();
  Serial.println("NRF initialized.");

  Serial.print("Connecting to ");
  Serial.println(WIFI_SSID);
  WiFi.begin(WIFI_SSID, WIFI_PASSWORD);
  while (WiFi.status() != WL_CONNECTED) {
    delay(500);
    Serial.print(".");
  }
  Serial.println("");
  Serial.println("WiFi connected.");

  configTime(NTP_OFFSET, 0, NTP_ADDRESS);
  lastNTPUpdate = millis();

  displayTicker.attach_ms(30, displayUpdater);
}

uint8_t wheelval = 0;

void loop() {

  updateTouch();

  if (WiFi.status() != WL_CONNECTED) {
    WiFi.reconnect();
  }

  // Periodically refresh NTP time
  if ((millis() - lastNTPUpdate) > (1000 * NTP_INTERVAL)) {
    configTime(NTP_OFFSET, 0, NTP_ADDRESS);
    lastNTPUpdate = millis();
  }
}

void displayUpdater() {
  if (isClock) {
    if(!getLocalTime(&timeinfo)){
      return;
    }

    unsigned long epoch = mktime(&timeinfo);
    if (epoch != prevEpoch) {
      displayClock();
      prevEpoch = epoch;
    }
  } 
  if (isWeather) {
    displayWeather();
    updateWeather();
  }
}

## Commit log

2025-01-20 Added .ino file
    The .ino file is added with the source Code for our Arduino project
2025-01-20 add .stl files
    [Box.stl, Box_for_printing.stl, Frame.stl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]
2025-01-21 fix code with functioning touch
    [config.h, display.h]
2025-01-21 add images, and xlsx
    [used_products_cost.xlsx]
2025-01-21 typo fix
    [used_products_cost.xlsx]
